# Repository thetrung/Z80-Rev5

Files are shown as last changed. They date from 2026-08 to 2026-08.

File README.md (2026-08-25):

# Z80-Rev5 
Rev.5 of Z80 system designed with STC8H8K64U, 512K SRAM/EEPROM.

### Note
I have never had a real working Z80 before so this board is designed to test that if I can get one.

### 3D Preview 
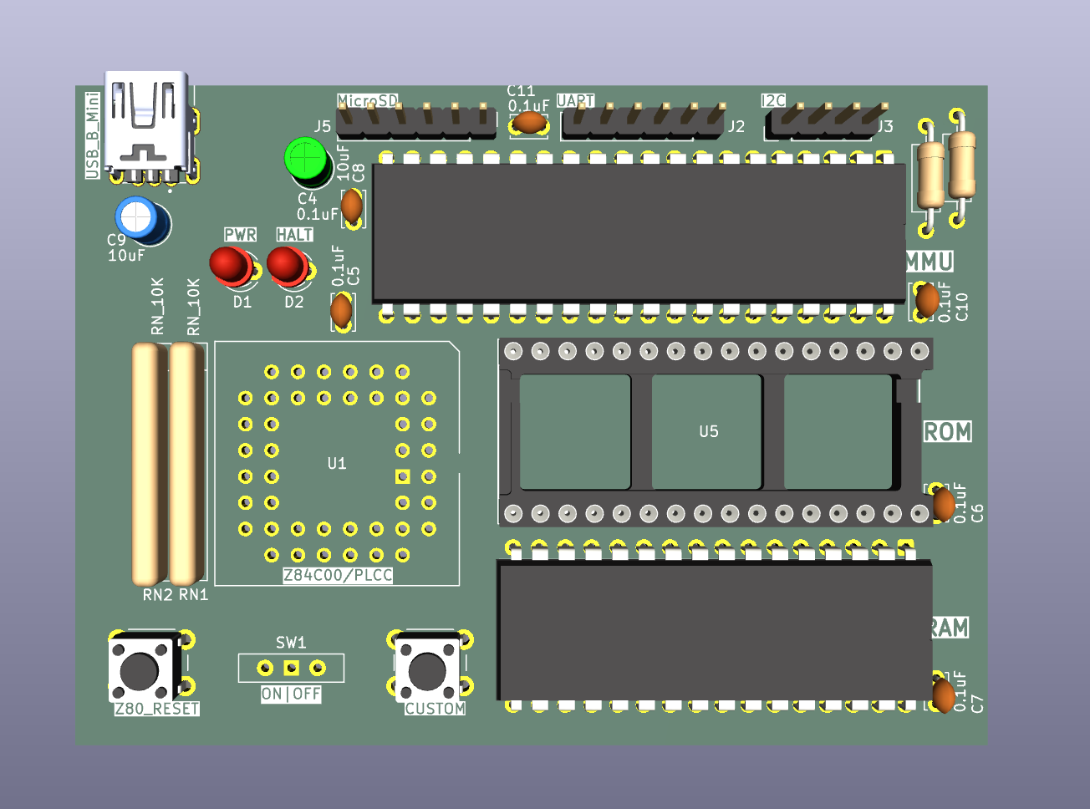
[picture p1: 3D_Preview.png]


### Placement (SilkScreen)
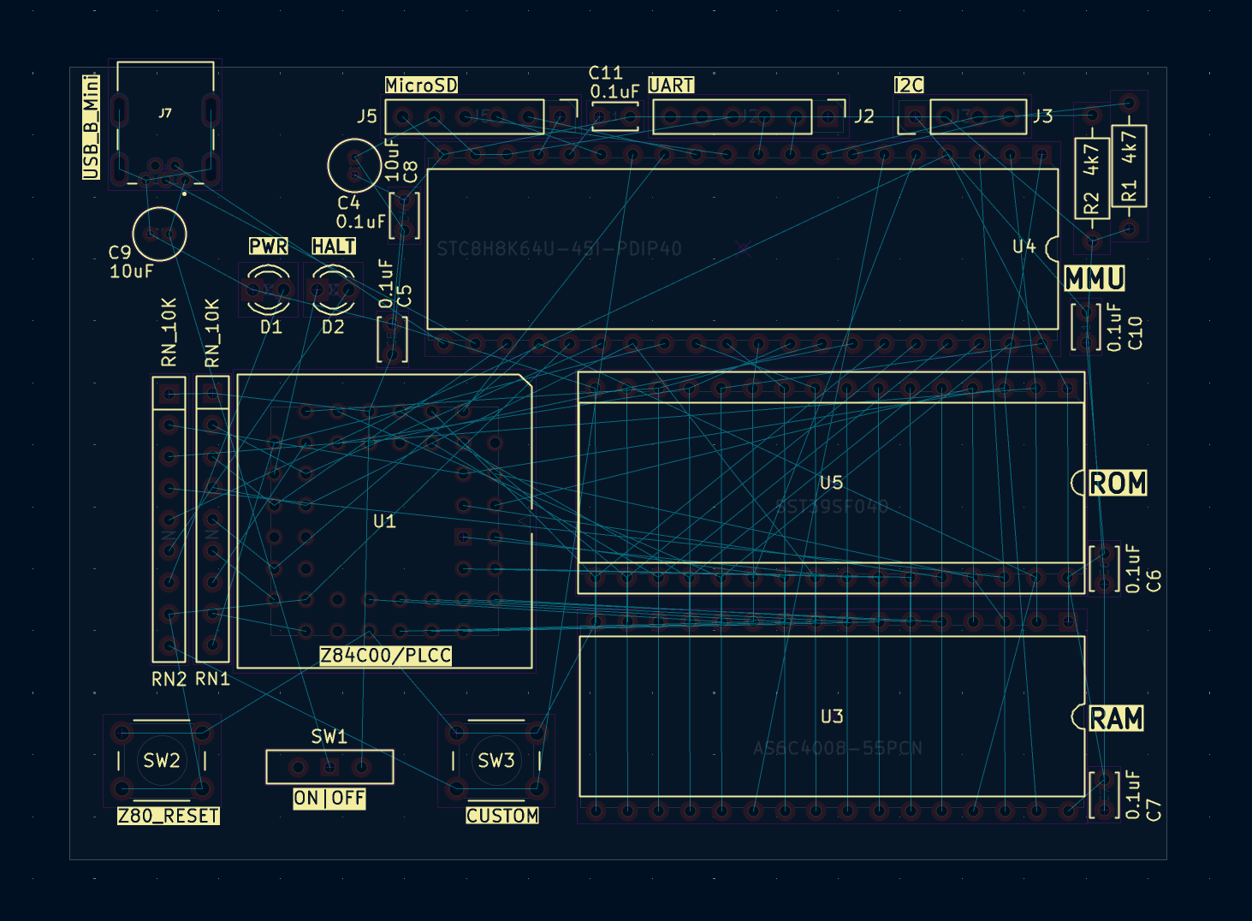
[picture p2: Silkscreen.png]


### Schematic 
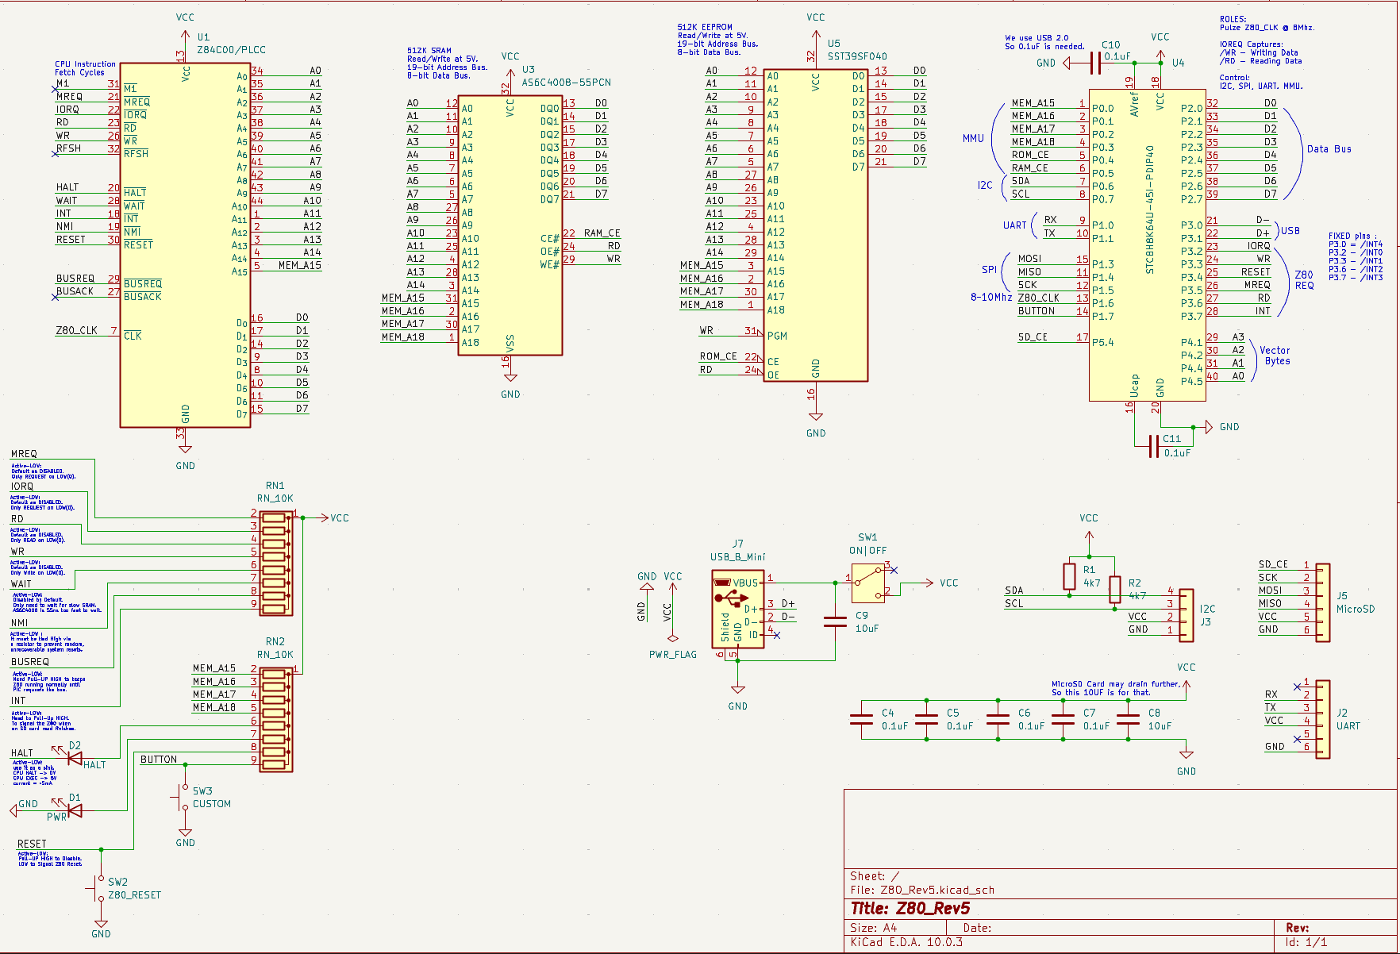
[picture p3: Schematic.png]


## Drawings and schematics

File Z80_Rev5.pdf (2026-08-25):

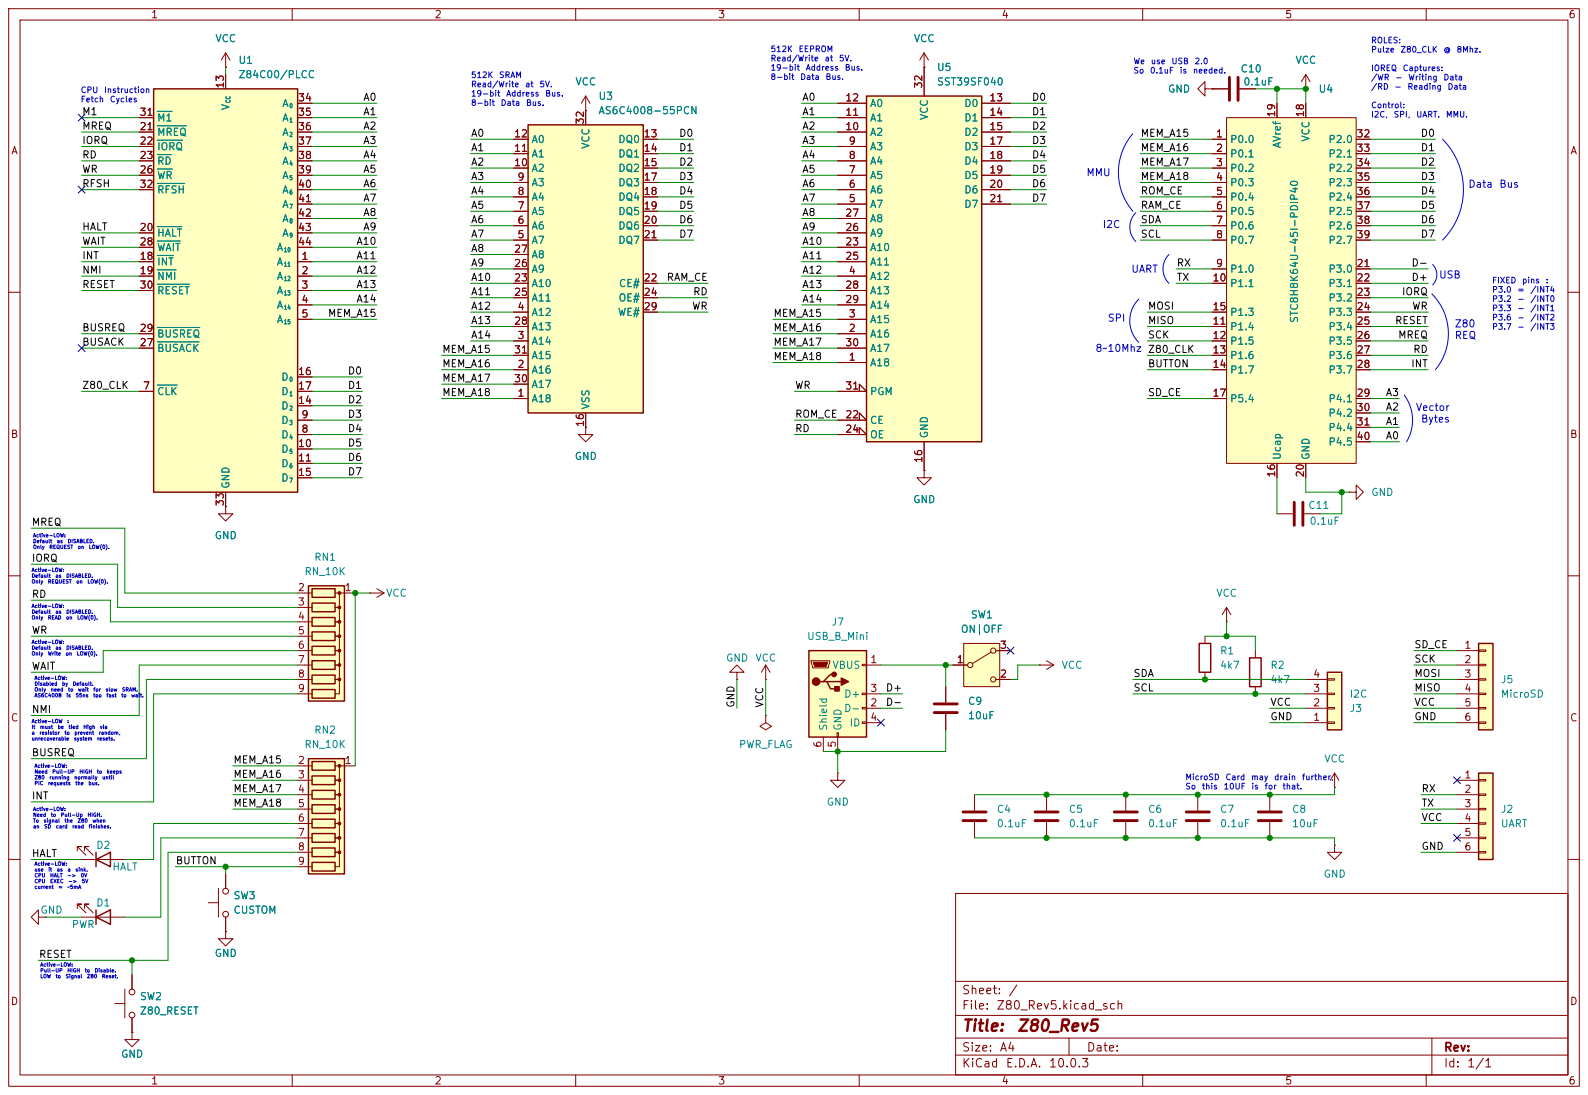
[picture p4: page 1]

VCC
RDM1 HALT
INT 18 NMI 19 HALT 20 MREQ 21

512K EEPROM
Read/Write at 5V. 19-bit Address Bus. 8-bit Data Bus.

IOREQ Captures: /WR - Writing Data /RD - Reading Data Control:

Active-LOW: Default as DISABLED. Only REQUEST on LOW(0).
IORQ

Active-LOW: Default as DISABLED. Only READ on LOW(0).

Active-LOW: Disabled by Default. Only need to wait for slow SRAM. AS6C4008 is 55ns too fast to wait.

Active-LOW :
It must be tied High via a resistor to prevent random, unrecoverable system resets.

Active-LOW: Need to Pull-Up HIGH. To signal the Z80 when an SD card read finishes. Active-LOW: use it as a sink. CPU HALT -> 0V CPU EXEC -> 5V

Active-LOW: Pull-UP HIGH to Disable. LOW to Signal Z80 Reset.

Size: A4 | Rev:
KiCad E.D.A. 10.0.3 | Id: 1/1

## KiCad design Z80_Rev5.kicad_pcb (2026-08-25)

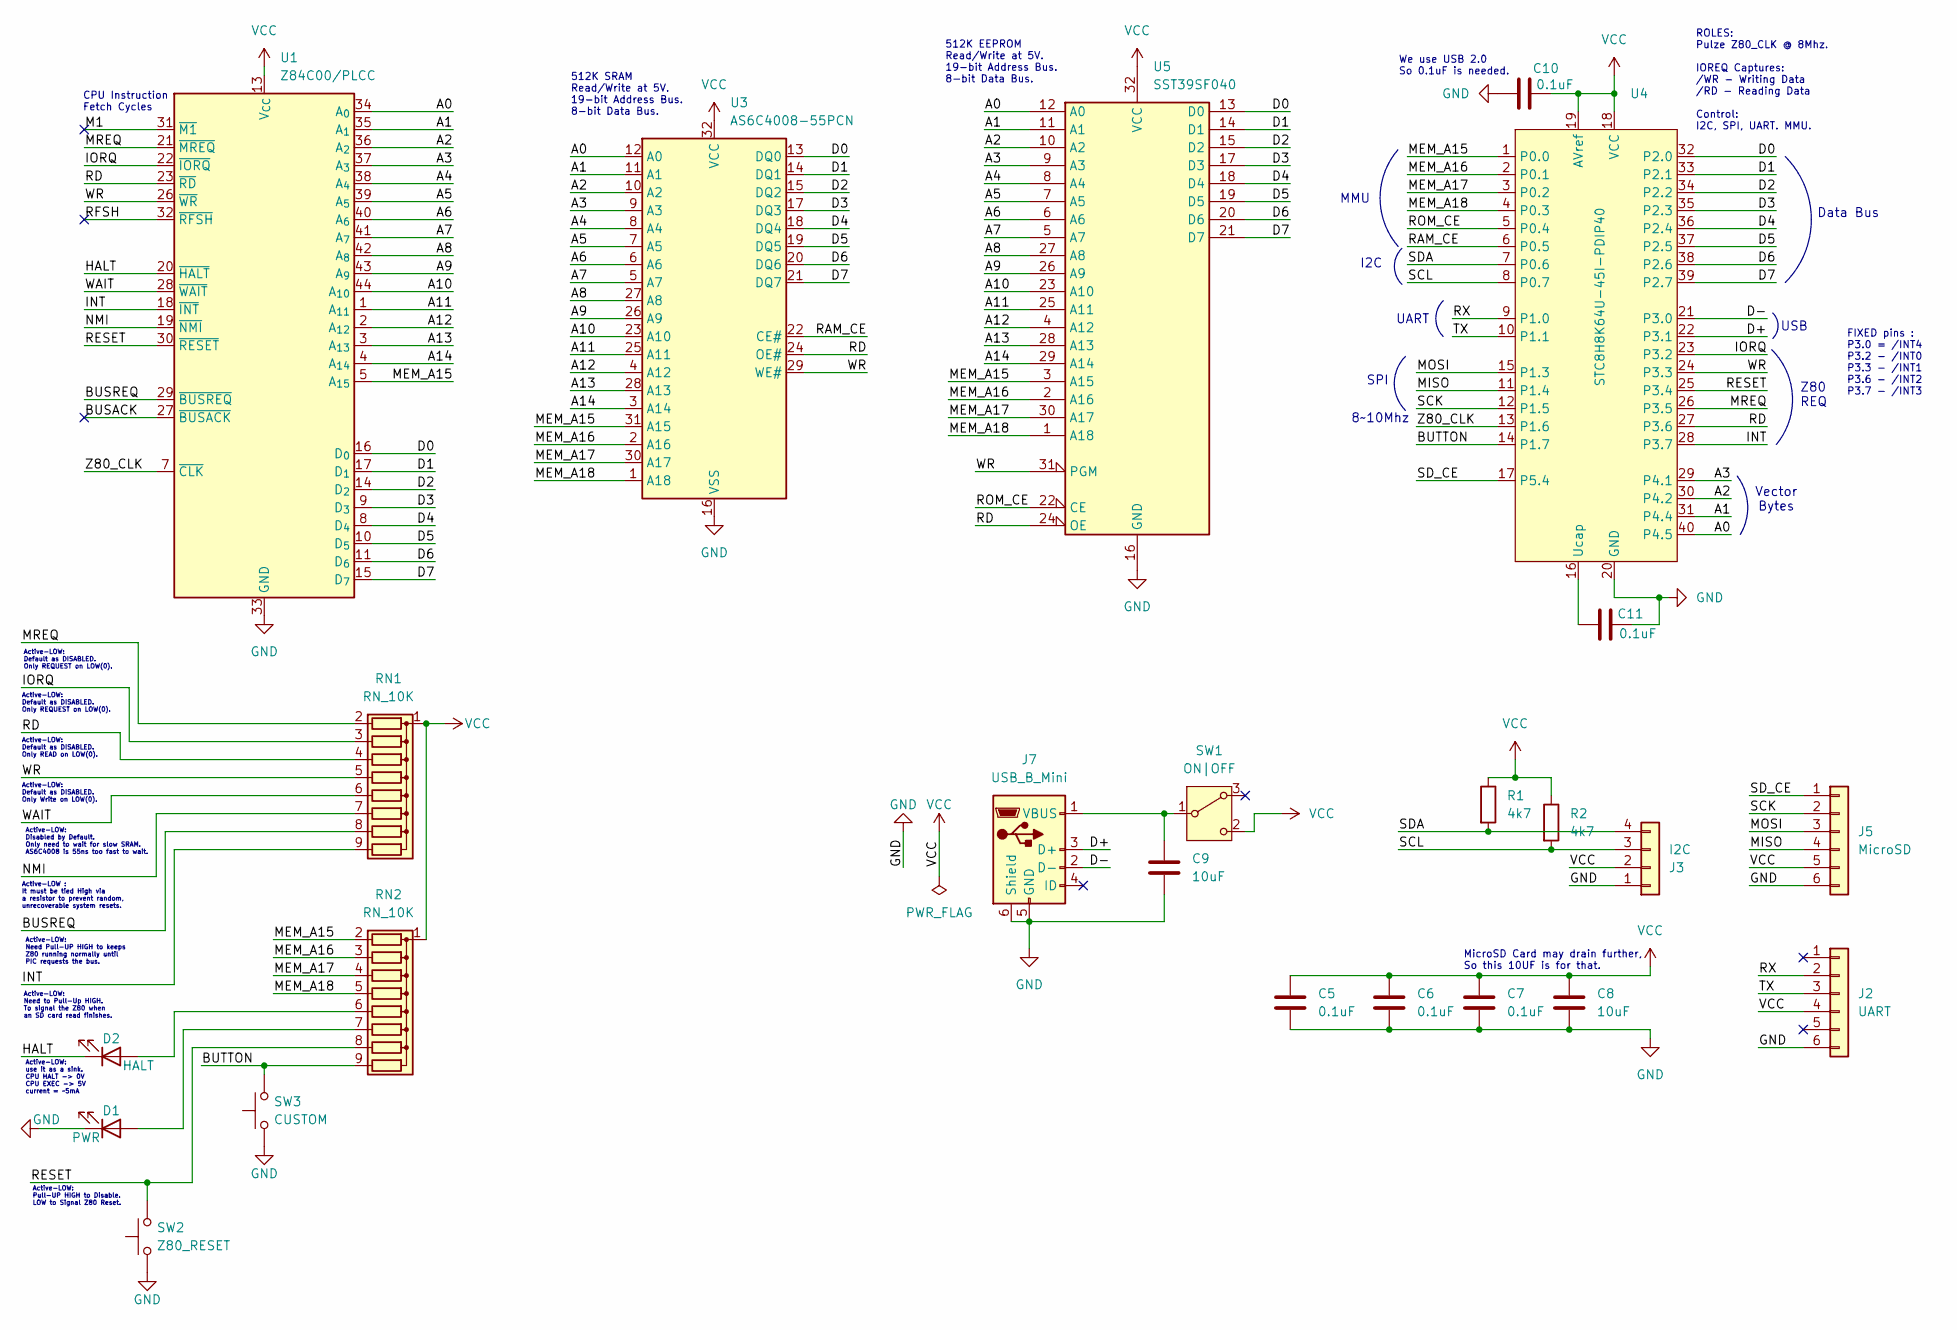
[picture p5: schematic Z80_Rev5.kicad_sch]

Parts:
C5, C6, C7, C10, C11: 0.1uF; C_Disc_D3.4mm_W2.1mm_P2.50mm
C8, C9: 10uF; C_Radial_D4.0mm_H5.0mm_P1.50mm
D1: PWR; LED_D3.0mm
D2: HALT; LED_D3.0mm
J2: UART; PinHeader_1x06_P2.54mm_Vertical
J3: I2C; PinHeader_1x04_P2.54mm_Vertical
J5: MicroSD; PinHeader_1x06_P2.54mm_Vertical
J7: USB_B_Mini; USB_MINI_B_90_Angled
R1, R2: 4k7; R_Axial_DIN0207_L6.3mm_D2.5mm_P10.16mm_Horizontal
RN1, RN2: RN_10K; R_Array_SIP9
SW1: ON|OFF; SW_Slide-03_Wuerth-WS-SLTV_10x2.5x6.4_P2.54mm
SW2: Z80_RESET; SW_PUSH_6mm
SW3: CUSTOM; SW_PUSH_6mm
U1: Z84C00/PLCC; PLCC-44_THT-Socket
U3: AS6C4008-55PCN; DIP-32_W15.24mm
U4: STC8H8K64U-45I-PDIP40; DIP-40_W15.24mm
U5: SST39SF040; DIP-32_W15.24mm_Socket

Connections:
/A0: U1.34 (A_{0}), U3.12 (A0), U4.40 (P4.5), U5.12 (A0)
/A1: U1.35 (A_{1}), U3.11 (A1), U4.31 (P4.4), U5.11 (A1)
/A2: U1.36 (A_{2}), U3.10 (A2), U4.30 (P4.2), U5.10 (A2)
/A3: U1.37 (A_{3}), U3.9 (A3), U4.29 (P4.1), U5.9 (A3)
/A4: U1.38 (A_{4}), U3.8 (A4), U5.8 (A4)
/A5: U1.39 (A_{5}), U3.7 (A5), U5.7 (A5)
/A6: U1.40 (A_{6}), U3.6 (A6), U5.6 (A6)
/A7: U1.41 (A_{7}), U3.5 (A7), U5.5 (A7)
/A8: U1.42 (A_{8}), U3.27 (A8), U5.27 (A8)
/A9: U1.43 (A_{9}), U3.26 (A9), U5.26 (A9)
/A10: U1.44 (A_{10}), U3.23 (A10), U5.23 (A10)
/A11: U1.1 (A_{11}), U3.25 (A11), U5.25 (A11)
/A12: U1.2 (A_{12}), U3.4 (A12), U5.4 (A12)
/A13: U1.3 (A_{13}), U3.28 (A13), U5.28 (A13)
/A14: U1.4 (A_{14}), U3.3 (A14), U5.29 (A14)
/BUSACK: U1.27 (~BUSACK)
/BUSREQ: RN1.8 (R7), U1.29 (~BUSREQ)
/BUTTON: RN2.9 (R8), SW3.2, U4.14 (P1.7)
/D0: U1.16 (D_{0}), U3.13 (DQ0), U4.32 (P2.0), U5.13 (D0)
/D1: U1.17 (D_{1}), U3.14 (DQ1), U4.33 (P2.1), U5.14 (D1)
/D2: U1.14 (D_{2}), U3.15 (DQ2), U4.34 (P2.2), U5.15 (D2)
/D3: U1.9 (D_{3}), U3.17 (DQ3), U4.35 (P2.3), U5.17 (D3)
/D4: U1.8 (D_{4}), U3.18 (DQ4), U4.36 (P2.4), U5.18 (D4)
/D5: U1.10 (D_{5}), U3.19 (DQ5), U4.37 (P2.5), U5.19 (D5)
/D6: U1.11 (D_{6}), U3.20 (DQ6), U4.38 (P2.6), U5.20 (D6)
/D7: U1.15 (D_{7}), U3.21 (DQ7), U4.39 (P2.7), U5.21 (D7)
/D+: J7.3 (D+), U4.22 (P3.1)
/D-: J7.2 (D-), U4.21 (P3.0)
/HALT: D2.1 (K), U1.20 (~HALT)
/INT: RN1.9 (R8), U1.18 (~INT), U4.28 (P3.7)
/IORQ: RN1.3 (R2), U1.22 (~IORQ), U4.23 (P3.2)
/M1: U1.31 (~M1)
/MEM_A15: RN2.2 (R1), U1.5 (A_{15}), U3.31 (A15), U4.1 (P0.0), U5.3 (A15)
/MEM_A16: RN2.3 (R2), U3.2 (A16), U4.2 (P0.1), U5.2 (A16)
/MEM_A17: RN2.4 (R3), U3.30 (A17), U4.3 (P0.2), U5.30 (A17)
/MEM_A18: RN2.5 (R4), U3.1 (A18), U4.4 (P0.3), U5.1 (A18)
/MISO: J5.4, U4.11 (P1.4)
/MOSI: J5.3, U4.15 (P1.3)
/MREQ: RN1.2 (R1), U1.21 (~MREQ), U4.26 (P3.5)
/NMI: RN1.7 (R6), U1.19 (~NMI)
/RAM_CE: U3.22 (CE#), U4.6 (P0.5)
/RD: RN1.4 (R3), U1.23 (~RD), U3.24 (OE#), U4.27 (P3.6), U5.24 (OE)
/RESET: RN2.8 (R7), SW2.2, U1.30 (~RESET), U4.25 (P3.4)
/RFSH: U1.32 (~RFSH)
/ROM_CE: U4.5 (P0.4), U5.22 (CE)
/RX: J2.2, U4.9 (P1.0)
/SCK: J5.2, U4.12 (P1.5)
/SCL: J3.3, R2.2, U4.8 (P0.7)
/SDA: J3.4, R1.2, U4.7 (P0.6)
/SD_CE: J5.1, U4.17 (P5.4)
/TX: J2.3, U4.10 (P1.1)
/WAIT: RN1.6 (R5), U1.28 (~WAIT)
/WR: RN1.5 (R4), U1.26 (~WR), U3.29 (WE#), U4.24 (P3.3), U5.31 (PGM)
/Z80_CLK: U1.7 (~CLK), U4.13 (P1.6)
GND: C5.1, C6.1, C7.1, C8.1, C9.1, C10.2, C11.2, D1.1 (K), J2.6, J3.1, J5.6, J7.5 (GND), J7.6 (Shield), SW2.1, SW3.1, U1.33 (GND), U3.16 (VSS), U4.20 (GND), U5.16 (GND)
unnamed: D1.2 (A), RN2.7 (R6)
unnamed: D2.2 (A), RN2.6 (R5)
unnamed: C9.2, J7.1 (VBUS), SW1.1 (B)
unnamed: C11.1, U4.16 (Ucap)
VCC: C5.2, C6.2, C7.2, C8.2, C10.1, J2.4, J3.2, J5.5, R1.1, R2.1, RN1.1 (common), RN2.1 (common), SW1.2 (C), U1.13 (V_{CC}), U3.32 (VCC), U4.18 (VCC), U4.19 (AVref), U5.32 (VCC)

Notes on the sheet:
Active-LOW: Default as DISABLED. Only REQUEST on LOW(0).
Active-LOW: Need to Pull-Up HIGH. To signal the Z80 when an SD card read finishes.
Data Bus
512K SRAM Read/Write at 5V. 19-bit Address Bus. 8-bit Data Bus.
Active-LOW: use it as a sink. CPU HALT -> 0V CPU EXEC -> 5V current = ~5mA
Active-LOW: Default as DISABLED. Only READ on LOW(0).
UART
MMU
ROLES: Pulze Z80_CLK @ 8Mhz. IOREQ Captures: /WR - Writing Data /RD - Reading Data Control: I2C, SPI, UART. MMU.
512K EEPROM Read/Write at 5V. 19-bit Address Bus. 8-bit Data Bus.
Active-LOW: Disabled by Default. Only need to wait for slow SRAM. AS6C4008 is 55ns too fast to wait.
Active-LOW: Need Pull-UP HIGH to keeps Z80 running normally until PIC requests the bus.
Vector Bytes
MicroSD Card may drain further, So this 10UF is for that.
Active-LOW : It must be tied High via a resistor to prevent random, unrecoverable system resets.
Active-LOW: Pull-UP HIGH to Disable. LOW to Signal Z80 Reset.
Active-LOW: Default as DISABLED. Only Write on LOW(0).
Z80 REQ
FIXED pins : P3.0 = /INT4 P3.2 - /INT0 P3.3 - /INT1 P3.6 - /INT2 P3.7 - /INT3
8~10Mhz
We use USB 2.0 So 0.1uF is needed.
CPU Instruction Fetch Cycles
USB
I2C
SPI

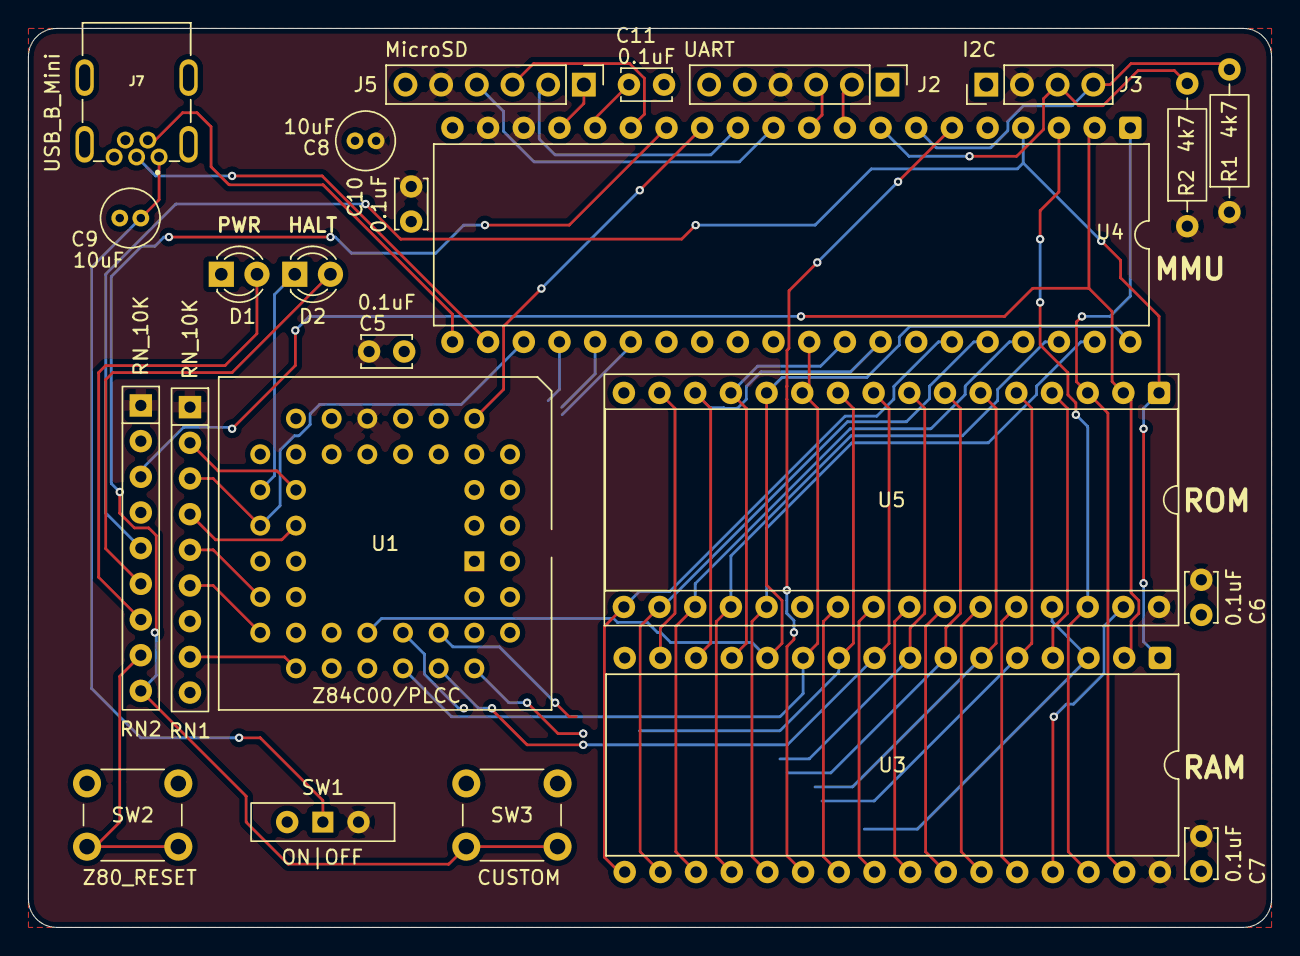
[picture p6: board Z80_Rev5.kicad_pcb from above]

Board: 2 copper layers, 88.5 x 64.0 mm, 24 parts (0 on the bottom side), 57 nets.

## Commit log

2026-08-25 init Z80-Rev.5 with STC8H8K64U-DIP40
    [Z80_Rev5.kicad_pcb, Z80_Rev5.kicad_sch]
2026-08-25 add sch + silk images.
    [Z80_Rev5.kicad_sch]
2026-08-25 refine STC8 pinmap.
    [Z80_Rev5.kicad_pcb, Z80_Rev5.kicad_sch]
2026-08-25 Remove C4 because too many of them.
    [Z80_Rev5.kicad_pcb, Z80_Rev5.kicad_sch]
